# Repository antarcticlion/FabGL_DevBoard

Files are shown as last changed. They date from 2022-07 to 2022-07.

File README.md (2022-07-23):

# FabGL_DevBoard
 FabGL development board using ESP32-DevkitC-V4

---

解説は後で書きます。

---

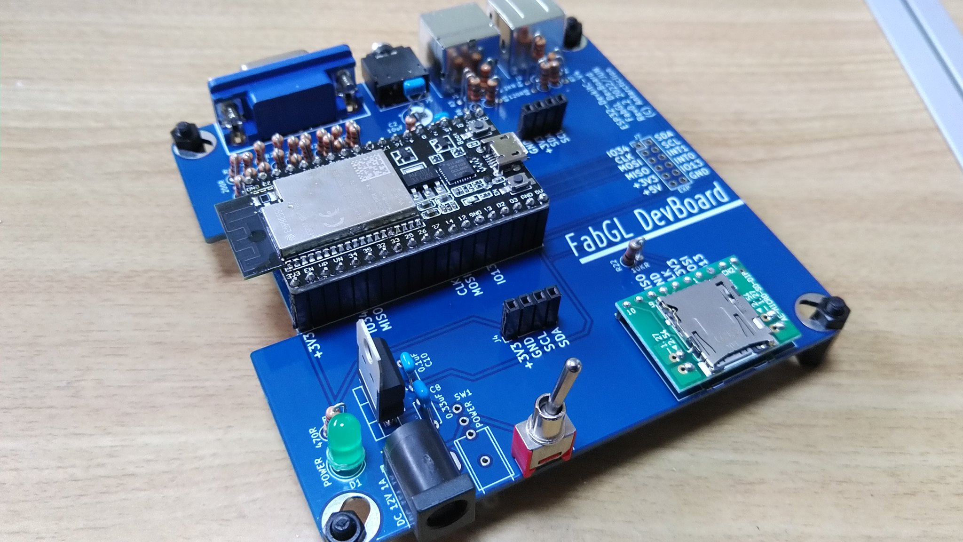
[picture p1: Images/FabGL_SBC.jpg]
FabGL DevBoard photo


---
# Lastest gerber

https://github.com/antarcticlion/FabGL_DevBoard/raw/main/FabGL_SBC/gerber/ESP32DevkitC-V4-SBC-FabGL_02.zip

---
# BOM

|番号|部品|数|
|:---|:---|:---|
| J1,J2 | ミニＤＩＮソケットfemale 6p | 2|
| J3 | マイクロSDソケット ヒロセDM3AT-SF-PEJM5 | 1|
| U1 | 1x19 ピンソケット | 2|
| U1 | ESP32-DebkitC-VE (Insert to pinsocket) | 1|
| R1～R4 | 2KR抵抗 7mm スルーホール | 4|
| R5～R8,R15,R26,R30 | 120R抵抗 7mm スルーホール | 7|
| R22 | 10KR抵抗 7mm スルーホール | 1|
| R34 | 470R抵抗 7mm スルーホール | 1|
| R9～R14,R16～R21,R23～R25,R27～R29 | 200R抵抗 7mm スルーホール | 18|
| J6 | DE15 Dsub-15P 3rows female horizontal pcb | 1|
| J5 | 3.5mmステレオミニジャック MJ-495A | 1|
| D1 | 5mm LED | 1|
| C2 | 10uF 2.5mm pitch MLCC | 1|
| C1,C10 | 0.1uF 5mm pitch MLCC | 2|
| C8 | 0.33uF 5mm pitch MLCC | 1|
| SW1 or SW2 | SPDT togle switch | 1|
| U7 | STMicroelectronics L7805CV | 1|
| J11 | DC Barreljack | 1|

---
# 取り扱いの注意点
・USBから給電するときはDCジャックの給電を止めてください。  
・ファームウェア更新時にはBootボタンを押す必要があります。Arduino IDE から「→」ボタンで転送を始めたら、しばらく待った後で"Connecting...."と表示された後ですぐbootボタンを押して、転送が開始されたら放してください。  
・I2Cは未チェックです。  
・ESP32-WROVERに対応するためピンアウトを一部変えています。SDカードやエキスパンダを使う場合、初期化時にピン番号を指定してください。  
| 信号 | ピン |
|:---|:---|
| MISO | 35 |
| MOSI | 12 |
| SCK | 14 |
| SS | 13 |

---

# Related Links

https://github.com/fdivitto/FabGL

---

# LICENCE
  
Copyright Antarcticlion 2022. This source describes Open Hardware and is licensed under the CERN-OHLW v2  
  
You may redistribute and modify this documentation and make products using it under the terms of the CERN-OHL-W v2 (https:/cern.ch/cern-ohl). This documentation is distributed WITHOUT ANY EXPRESS OR IMPLIED WARRANTY, INCLUDING OF MERCHANTABILITY, SATISFACTORY QUALITY AND FITNESS FOR A PARTICULAR PURPOSE. Please see the CERN-OHL-W v2 for applicable conditions. Source location: https://github.com/antarcticlion/RGB_UNICONV As per CERN-OHL-W v2 section 4.1, should You produce hardware based on these sources, You must maintain the Source Location visible on the external case of the White Rabbit switch or other product you make using this documentation.  
  
 CERN Open Hardware Licence Version 2 - Weakly Reciprocal
- https://spdx.org/licenses/CERN-OHL-W-2.0.html  
- https://github.com/antarcticlion/RGB_UNICONV/raw/main/cern_ohl_w_v2.pdf PDF  
- https://github.com/antarcticlion/RGB_UNICONV/raw/main/cern_ohl_w_v2_howto.pdf PDF

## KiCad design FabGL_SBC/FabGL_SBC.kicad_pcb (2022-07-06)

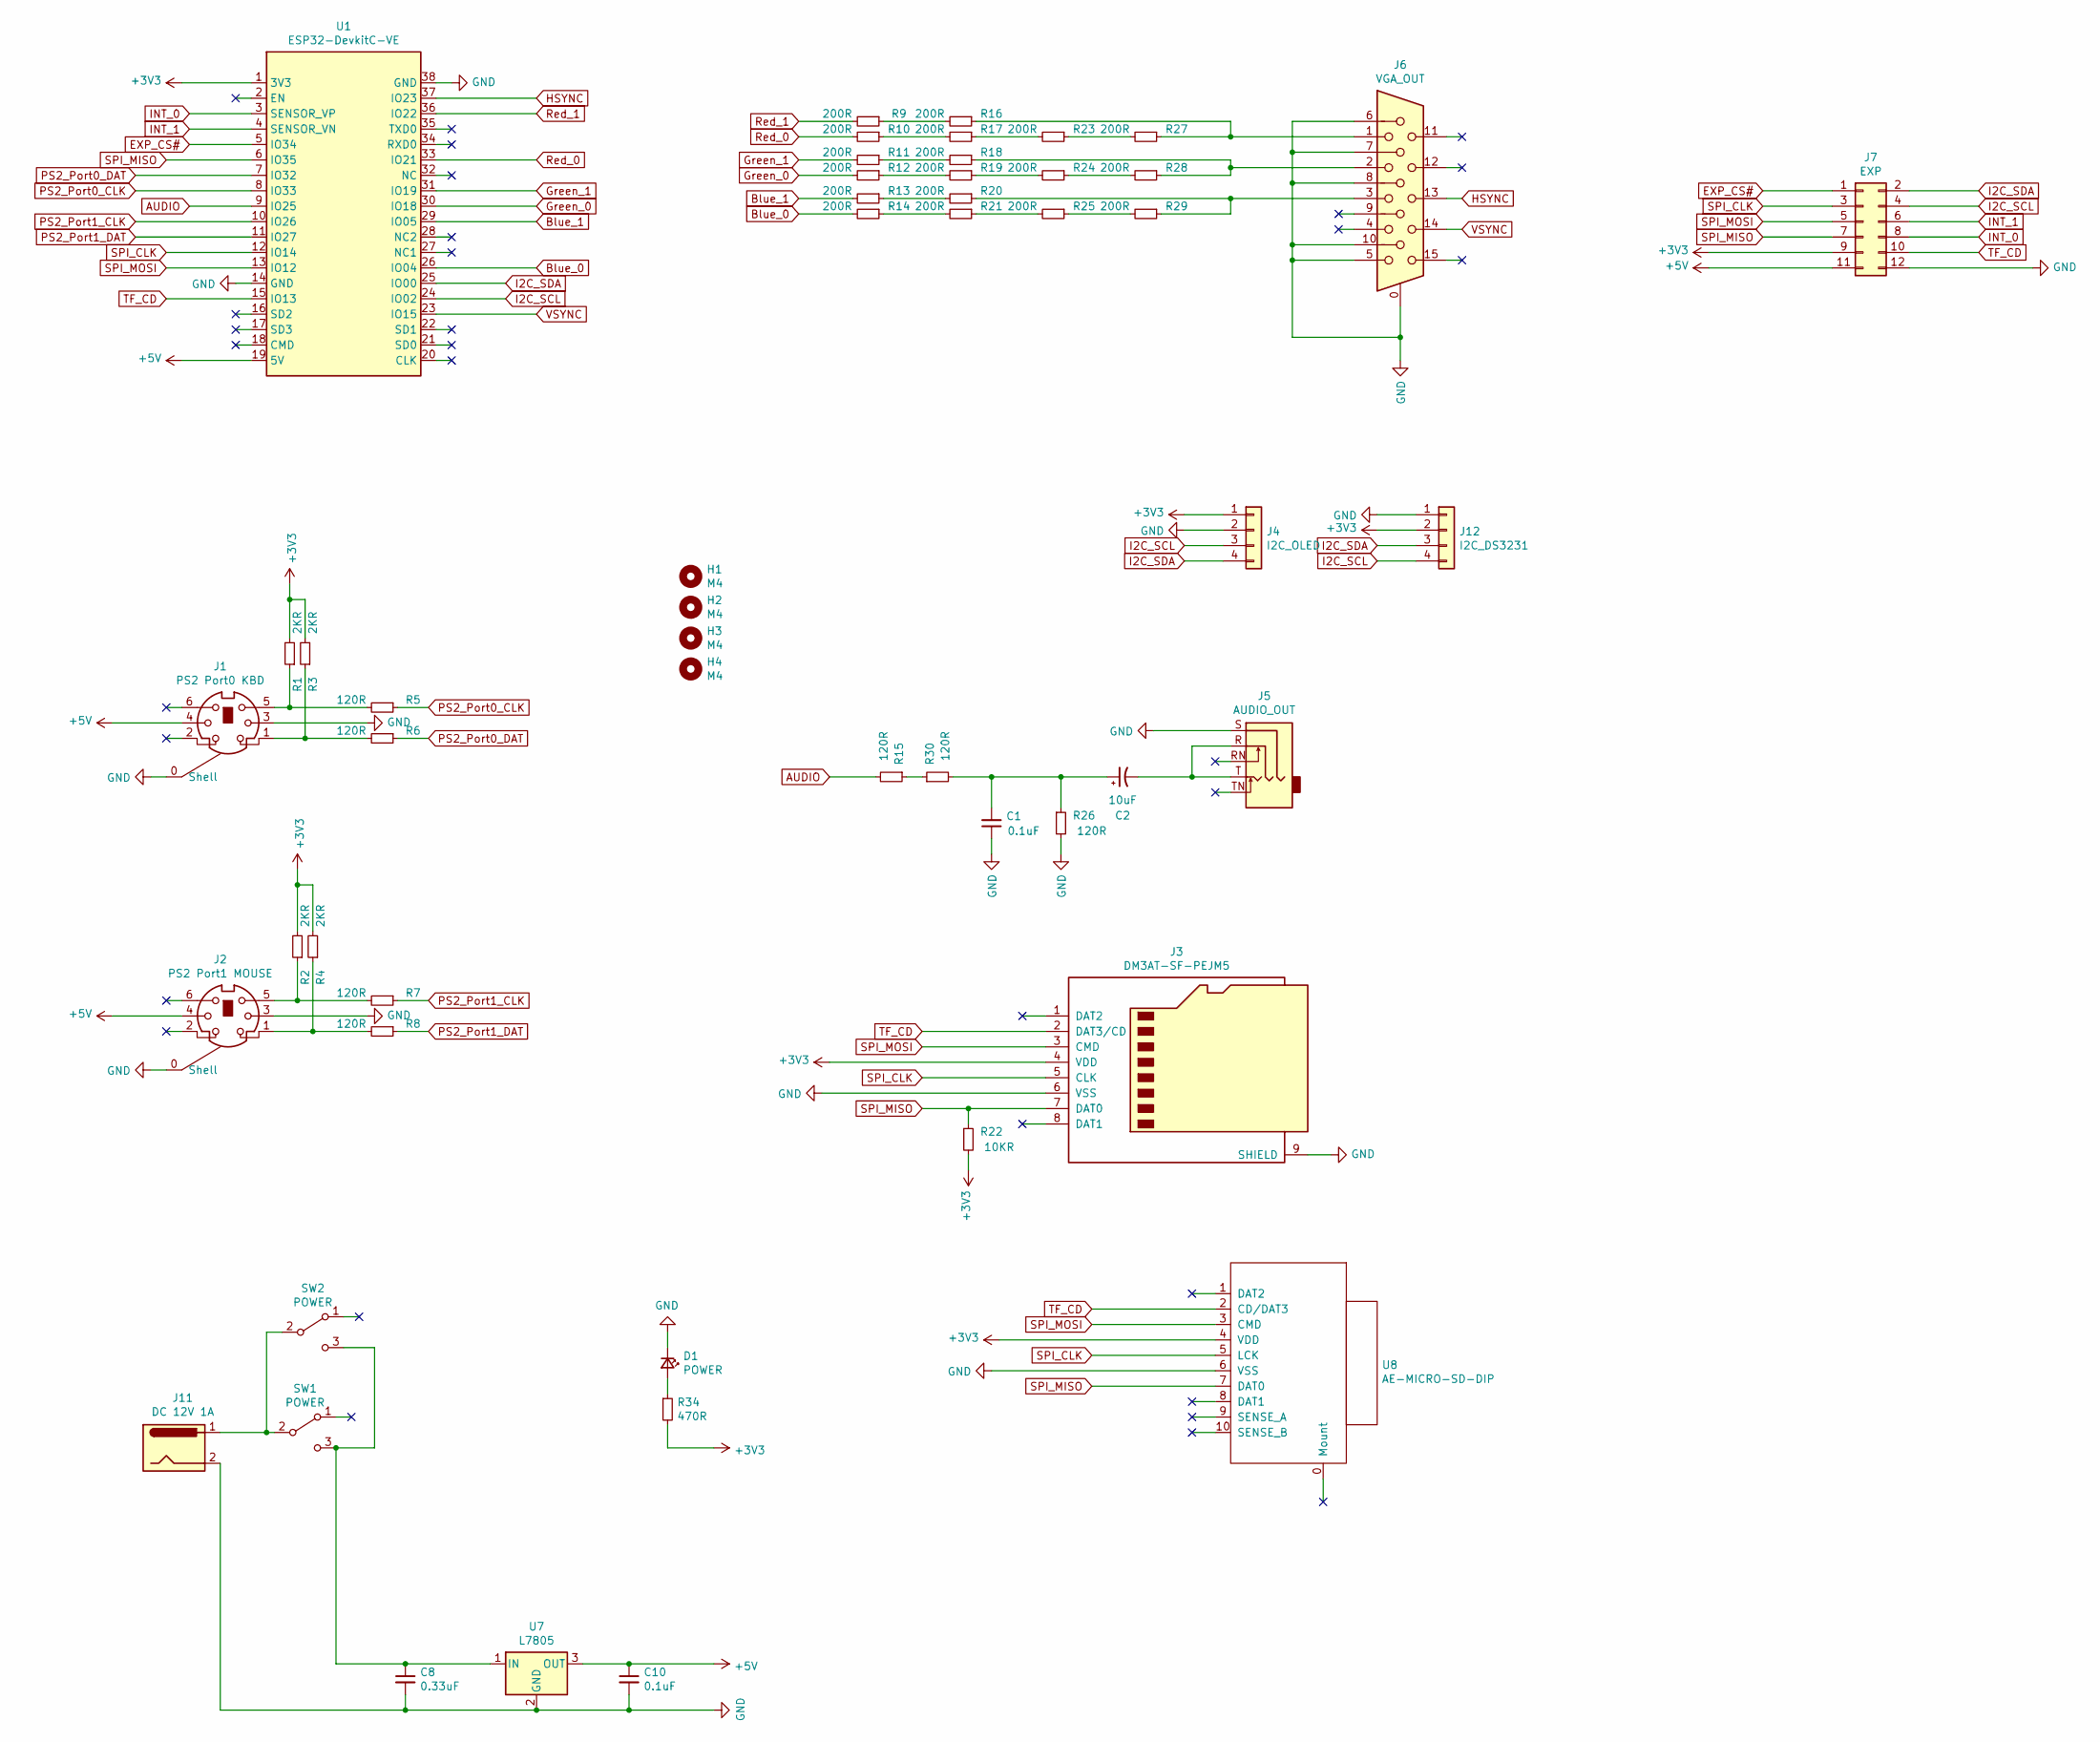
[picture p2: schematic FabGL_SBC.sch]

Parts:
C1, C10: 0.1uF; C_Disc_D5.0mm_W2.5mm_P5.00mm
C2: 10uF; CP_Radial_D6.3mm_P2.50mm
C8: 0.33uF; C_Disc_D5.0mm_W2.5mm_P5.00mm
D1: POWER; LED_D5.0mm
H1, H2, H3, H4: M4; MountingHole_4.3mm_M4
J1: PS2 Port0 KBD; mini DIN 6 PCB
J2: PS2 Port1 MOUSE; mini DIN 6 PCB
J3: DM3AT-SF-PEJM5; microSD_HC_Hirose_DM3AT-SF-PEJM5
J4: I2C_OLED; PinHeader_1x04_P2.54mm_Vertical
J5: AUDIO_OUT; PJ-3900-04
J6: VGA_OUT; DB_15F-VGA_L
J7: EXP; PinHeader_2x06_P2.54mm_Vertical
J11: DC 12V 1A; BarrelJack_Horizontal
J12: I2C_DS3231; PinHeader_1x04_P2.54mm_Vertical
R1, R2, R3, R4: 2KR; R_Axial_DIN0207_L6.3mm_D2.5mm_P2.54mm_Vertical
R5, R6, R7, R8, R15, R26, R30: 120R; R_Axial_DIN0207_L6.3mm_D2.5mm_P2.54mm_Vertical
R9, R10, R11, R12, R13, R14, R16, R17, R18, R19, R20, R21, R23, R24, R25, R27, R28, R29: 200R; R_Axial_DIN0207_L6.3mm_D2.5mm_P2.54mm_Vertical
R22: 10KR; R_Axial_DIN0207_L6.3mm_D2.5mm_P2.54mm_Vertical
R34: 470R; R_Axial_DIN0207_L6.3mm_D2.5mm_P2.54mm_Vertical
SW1: POWER; 2MS1T1B4M7QES
SW2: POWER; PinHeader_1x03_P2.54mm_Vertical
U1: ESP32-DevkitC-VE; ESP32-DevkitC-V4
U7: L7805; TO-220-3_Vertical
U8: AE-MICRO-SD-DIP

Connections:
+3V3: J3.4 (VDD), J4.1, J7.9, J12.2, R1.2, R2.2, R3.2, R4.2, R22.2, R34.2, U1.1 (3V3), U8.4 (VDD)
+5V: C10.1, J1.4, J2.4, J7.11, U1.19 (5V), U7.3 (OUT)
AUDIO: R15.2, U1.9 (IO25)
Blue_0: R14.2, U1.26 (IO04)
Blue_1: R13.2, U1.29 (IO05)
EXP_CS#: J7.1, U1.5 (IO34)
GND: C1.1, C8.2, C10.2, D1.1 (K), J1.0 (Shell), J1.3, J2.0 (Shell), J2.3, J3.6 (VSS), J3.9 (SHIELD), J4.2, J5.S, J6.0, J6.5, J6.6, J6.7, J6.8, J6.10, J7.12, J11.2, J12.1, R26.2, U1.14 (GND), U1.38 (GND), U7.2 (GND), U8.6 (VSS)
Green_0: R12.2, U1.30 (IO18)
Green_1: R11.2, U1.31 (IO19)
HSYNC: J6.13, U1.37 (IO23)
I2C_SCL: J4.3, J7.4, J12.4, U1.24 (IO02)
I2C_SDA: J4.4, J7.2, J12.3, U1.25 (IO00)
INT_0: J7.8, U1.3 (SENSOR_VP)
INT_1: J7.6, U1.4 (SENSOR_VN)
unnamed: C1.2, C2.1, R26.1, R30.2
unnamed: C2.2, J5.R, J5.T
unnamed: C8.1, SW1.3 (C), SW2.3 (C), U7.1 (IN)
unnamed: D1.2 (A), R34.1
unnamed: J1.1, R3.1, R6.2
unnamed: J1.5, R1.1, R5.2
unnamed: J2.1, R4.1, R8.2
unnamed: J2.5, R2.1, R7.2
unnamed: J6.1, R16.1, R27.1
unnamed: J6.2, R18.1, R28.1
unnamed: J6.3, R20.1, R29.1
unnamed: J11.1, SW1.2 (B), SW2.2 (B)
unnamed: R10.1, R17.2
unnamed: R11.1, R18.2
unnamed: R12.1, R19.2
unnamed: R13.1, R20.2
unnamed: R14.1, R21.2
unnamed: R15.1, R30.1
unnamed: R9.1, R16.2
unnamed: R17.1, R23.2
unnamed: R19.1, R24.2
unnamed: R21.1, R25.2
unnamed: R23.1, R27.2
unnamed: R24.1, R28.2
unnamed: R25.1, R29.2
PS2_Port0_CLK: R5.1, U1.8 (IO33)
PS2_Port0_DAT: R6.1, U1.7 (IO32)
PS2_Port1_CLK: R7.1, U1.10 (IO26)
PS2_Port1_DAT: R8.1, U1.11 (IO27)
Red_0: R10.2, U1.33 (IO21)
Red_1: R9.2, U1.36 (IO22)
SPI_CLK: J3.5 (CLK), J7.3, U1.12 (IO14), U8.5 (LCK)
SPI_MISO: J3.7 (DAT0), J7.7, R22.1, U1.6 (IO35), U8.7 (DAT0)
SPI_MOSI: J3.3 (CMD), J7.5, U1.13 (IO12), U8.3 (CMD)
TF_CD: J3.2 (DAT3/CD), J7.10, U1.15 (IO13), U8.2 (CD/DAT3)
VSYNC: J6.14, U1.23 (IO15)

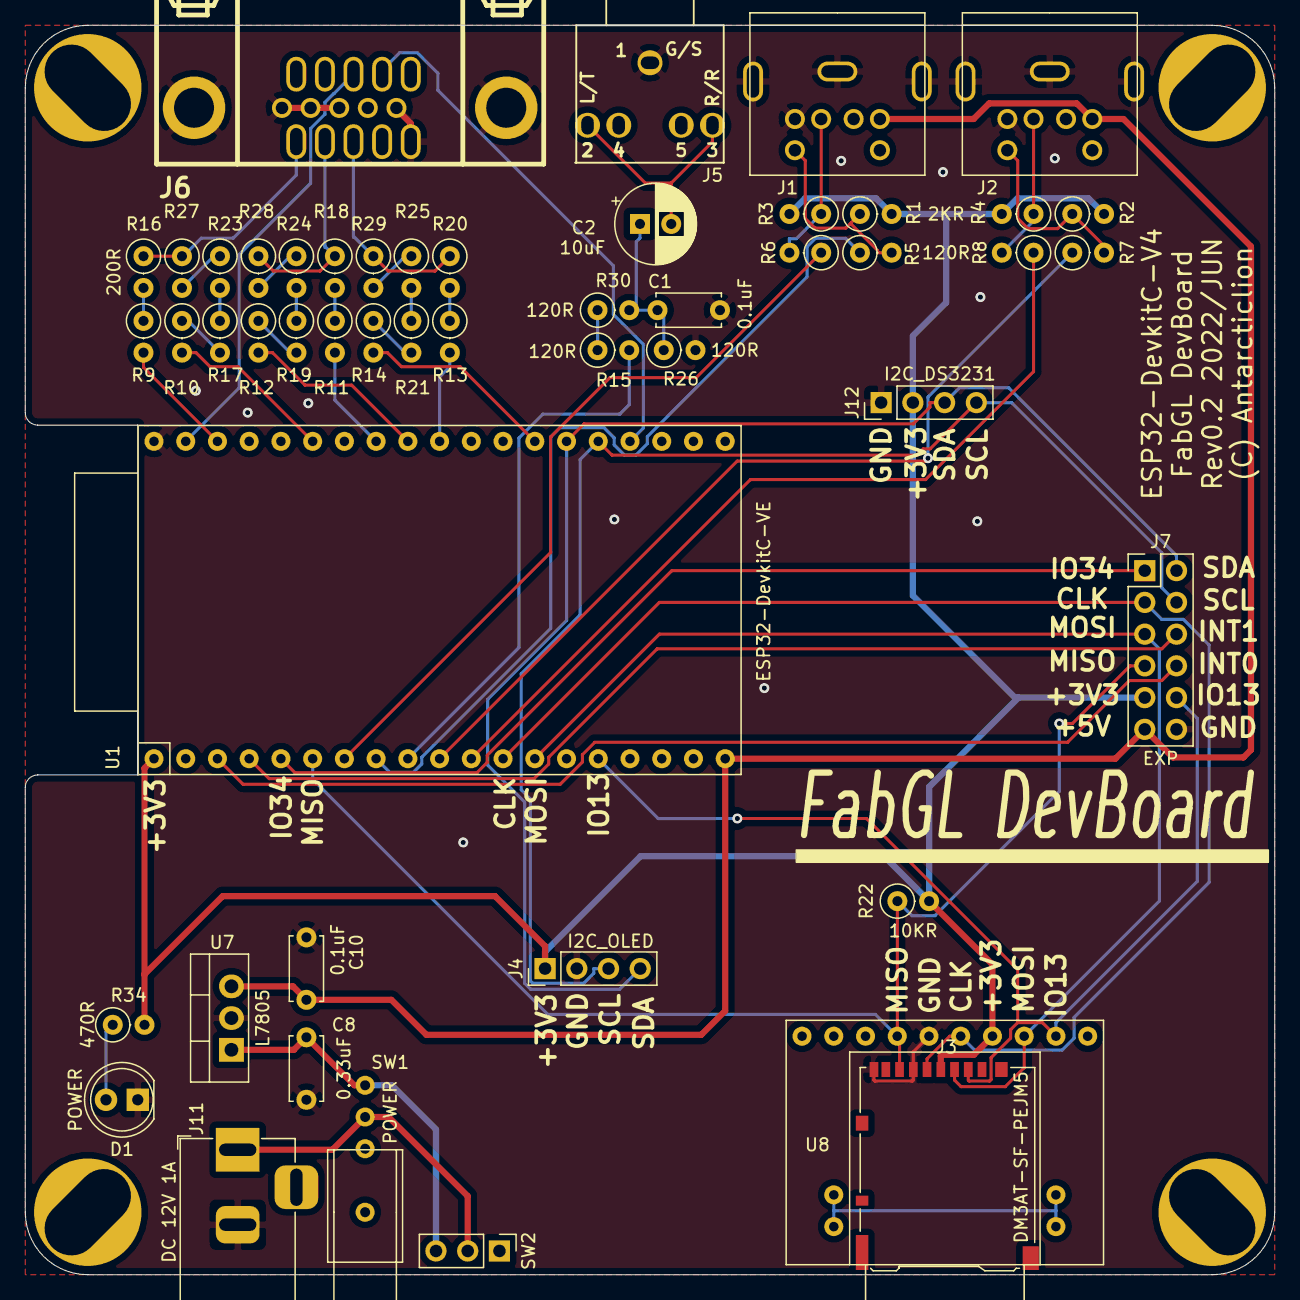
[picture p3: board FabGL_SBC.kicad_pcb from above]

Board: 2 copper layers, 100.0 x 100.0 mm, 54 parts (0 on the bottom side), 50 nets.
